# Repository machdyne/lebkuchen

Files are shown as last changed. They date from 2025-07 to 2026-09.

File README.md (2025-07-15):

# Lebkuchen Computer

Lebkuchen is an FPGA computer based on the GateMate A1.

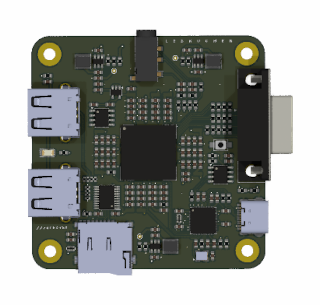
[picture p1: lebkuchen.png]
Lebkuchen


This repo contains schematics, PCB layouts, pinouts, a 3D-printable case, example gateware and documentation.

Find more information on the [Lebkuchen product page](https://machdyne.com/product/lebkuchen-computer/).

## Programming Lebkuchen 

Lebkuchen can be programmed over USB-C or by copying gateware to a MicroSD card (not yet implemented). The FPGA is configured by the onboard RP2040, which can load the configuration from onboard flash, a FAT-formatted MicroSD card or over the USB-JTAG bridge.

### JTAG

Program the FPGA configuration SRAM:

```
openFPGALoader -c dirtyJtag image.bit
```

### 3.5mm TRRS Audio Jack

| Pin | Signal |
| --- | --- |
| T | Left Audio |
| R1 | Right Audio |
| R2 | Composite Video |
| S | GND |

## Resources

 * [fpga-dac audio player](https://github.com/machdyne/fpga-dac)

## License

The contents of this repo are released under the [Lone Dynamics Open License](LICENSE.md).

Note: You can use these designs for commercial purposes but we ask that instead of producing exact clones, that you either replace our trademarks and logos with your own or add your own next to ours.

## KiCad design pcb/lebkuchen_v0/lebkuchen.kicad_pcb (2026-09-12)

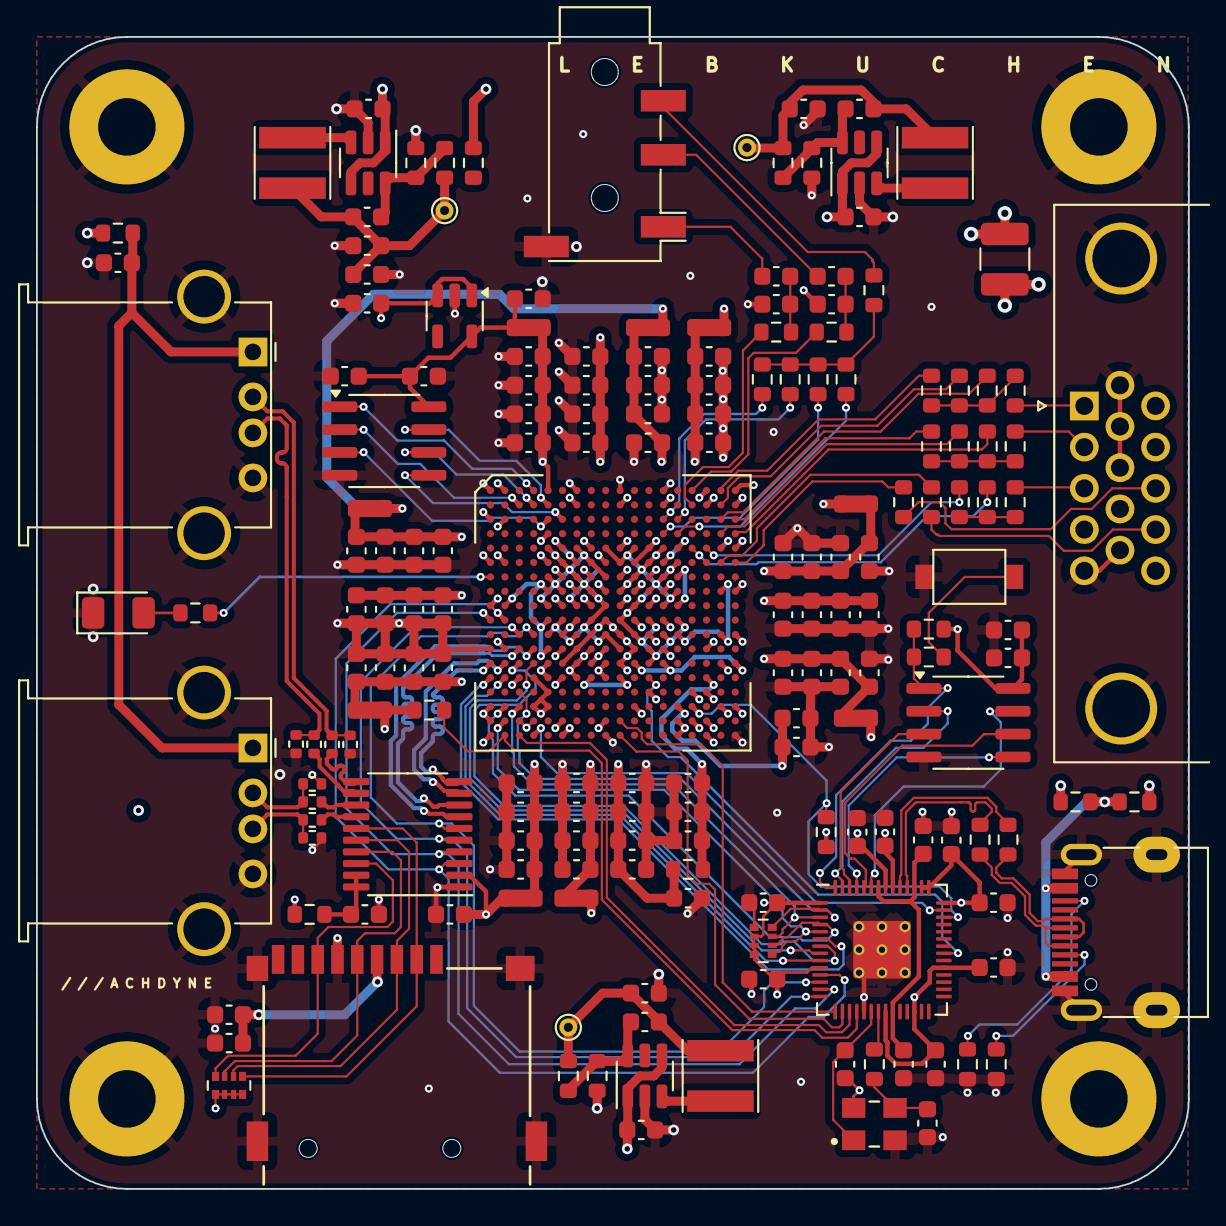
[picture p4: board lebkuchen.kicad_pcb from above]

Board: 4 copper layers, 64.0 x 64.0 mm, 185 parts (0 on the bottom side), 116 nets.

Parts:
C1, C2, C3, C12, C16, C18, C19, C27, C28, C36, C37, C45, C46, C55, C56: 2.2uF; C_0603_1608Metric
C4, C5, C6, C21, C22, C29, C30, C38, C39, C47, C48, C57, C58: 470nF; C_0603_1608Metric
C7: 220nF; C_0603_1608Metric
C8, C9, C10, C11, C17, C20, C23, C24, C31, C32, C40, C41, C49, C50, C59, C60, C64, C65, C67, C68, C69, C71, C83, C84, C85, C86, C87, C88, C90, C91, C95: 100nF; C_0603_1608Metric
C13, C14, C15, C25, C26, C33, C34, C42, C43, C51, C52, C61, C62: 10nF; C_0603_1608Metric
C35, C66, C89, C96, C97: 1uF; C_0603_1608Metric
C44, C80, C81: 22uF; C_0603_1608Metric
C53, C78, C79, C92, C93, C94: 10uF; C_0603_1608Metric
C54, C63: 15pF; C_0603_1608Metric
C72, C73, C74: 4.7uF; C_0603_1608Metric
C75, C76, C77: 10pF; C_0603_1608Metric
D2: LED; LED_1206_3216Metric
F1: Polyfuse; Fuse_1210_3225Metric
FB1, FB2, FB3, FB4: Ferrite_Bead; R_0603_1608Metric
H1, H2, H3, H4: MountingHole_Pad; MountingHole_3.2mm_M3_Pad
J1: TYPE-C-31-M-12-FIXED; USB_C_Receptacle_HRO_TYPE-C-31-M-12-BIG-PADS-PASTE
J3: AudioJack4; Jack_3.5mm_PJ320D_Horizontal
J4: MICROSD; SDCARD
J5, J6: USB_A; USB_A_Stewart_SS-52100-001_Horizontal
L1, L2, L3: 2.2uH; L_Taiyo-Yuden_MD-4040
R1: 4K7; R_0603_1608Metric
R2, R20: 5K1; R_0603_1608Metric
R6, R38: 10K; R_0603_1608Metric
R9, R11, R12, R13, R14, R16, R17, R18, R19: 0R; LD-NETTIE-0603
R10, R15: 27R; R_0603_1608Metric
R23, R24: 200K; R_0603_1608Metric
R25: 44K2; R_0603_1608Metric
R26, R29: 150K; R_0603_1608Metric
R27: 47K; R_0603_1608Metric
R28: 100K; R_0603_1608Metric
R30: 22R; R_0603_1608Metric
R31, R32, R33, R34: 22R; R_0402_1005Metric
R37, R39, R44, R51, R54, R58: 1K; R_0603_1608Metric
R40, R41, R67, R68: 100R; R_0603_1608Metric
R42, R52, R56, R60: 270R; R_0603_1608Metric
R43, R53, R57, R61: 536R; R_0603_1608Metric
R45: 2K; R_0603_1608Metric
R47, R64, R65, R66: 51R; R_0603_1608Metric
R55, R59, R62, R63: 15K; R_0402_1005Metric
RN1: 20K; R_Array_Convex_4x0402
RN2: 4K7; R_Array_Convex_4x0402
SW1: BOOT; Button_2P_3x4mm
TP1: TP_PWR3V3; TestPoint_THTPad_D1.0mm_Drill0.5mm
TP2: TP_PWR2V5; TestPoint_THTPad_D1.0mm_Drill0.5mm
TP3: TP_PWR1V0; TestPoint_THTPad_D1.0mm_Drill0.5mm
U1: CCGM1A1; BGA-324_15.0x15.0mm_Layout18x18_P0.8mm_Ball0.5mm_Pad0.4mm_N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
U2: RP2040; RP2040-QFN-56-OFFICIAL
U3: APS6404L-SQN-SN; SOIC-8_3.9x4.9mm_P1.27mm
U4: LSF0108PWR; TSSOP-20_4.4x6.5mm_P0.65mm
U5: AT25FF321A-SSHN-B; SOIC-8_3.9x4.9mm_P1.27mm
U7: NCP164ASN180T1G; TSOT-23-5
U8, U9, U10: TLV62569DDC; SOT-23-6
VGA1: DB15_Female_MountingHoles; DSUB-15-HD_Female_Horizontal_P2.29x1.98mm_EdgePinOffset3.03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
Y2: ECS-80-12-33-JGN-TR-12MHZ; XTAL_ECS-240-8-33-AGN-TR

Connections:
/AUDIO_L: R40.1, U1.B15 (IO_EB_A8)
/AUDIO_LC: C92.1, J3.T
/AUDIO_R: R41.1, U1.A15 (IO_EB_B8)
/AUDIO_RC: C93.1, J3.R1
/BOOT: R39.1, SW1.1
/CDONE: U1.V3 (IO_WA_B2/CFG_DONE), U2.17 (GPIO14)
/CFAILED: R1.2, U1.V2 (IO_WA_A2/~CFG_FAILED), U2.18 (GPIO15)
/CFG_MD3: U1.V4 (CFG_MD3/IO_WA_B1), U2.41 (GPIO29/ADC3)
/CLKRP: U1.P12 (CLK1/IO_SB_A7), U2.35 (GPIO23)
/CSPI_MISO: U1.P1 (IO_WA_A7/SPI_D1), U2.6 (GPIO4)
/CSPI_MOSI: U1.P2 (IO_WA_B7/SPI_D0), U2.9 (GPIO7)
/CSPI_SCK: U1.N4 (IO_WA_B8/SPI_CLK), U2.8 (GPIO6)
/CSPI_SS: U1.N3 (IO_WA_A8/~SPI_CS), U2.7 (GPIO5)
/JTAG_TCK: RN2.4 (R4.1), U1.R3 (JTAG_TCK/IO_WA_A5), U2.2 (GPIO0)
/JTAG_TDI: RN2.2 (R2.1), U1.T2 (JTAG_TDI/IO_WA_A4), U2.4 (GPIO2)
/JTAG_TDO: RN2.1 (R1.1), U1.U2 (JTAG_TDO/IO_WA_B3), U2.5 (GPIO3)
/JTAG_TMS: RN2.3 (R3.1), U1.T3 (JTAG_TMS/IO_WA_B4), U2.3 (GPIO1)
/LED: R51.1, U1.G1 (IO_WC_A0)
/PWR1V0: C1.2, C2.2, C4.2, C5.2, C9.2, C10.2, C13.2, C14.2, C18.2, C19.2, C20.2, C21.2, C22.2, C23.2, C24.2, C25.2, C26.2, C77.1, C80.1, C81.1, L3.2, R28.1, R30.2, TP3.1, U1.F9 (VDD), U1.G6 (VDD), U1.G8 (VDD), U1.G10 (VDD), U1.G12 (VDD), U1.H7 (VDD), U1.H9 (VDD), U1.H11 (VDD), U1.H13 (VDD), U1.J6 (VDD), U1.J8 (VDD), U1.J10 (VDD), U1.J12 (VDD), U1.K7 (VDD), U1.K9 (VDD), U1.K11 (VDD), U1.K13 (VDD), U1.L6 (VDD), U1.L8 (VDD), U1.L10 (VDD), U1.L12 (VDD), U1.M7 (VDD), U1.M9 (VDD), U1.M11 (VDD), U1.M13 (VDD), U1.N6 (VDD), U1.N8 (VDD), U1.N10 (VDD)
/PWR1V0RP: C64.1, C68.1, U2.23 (DVDD), U2.45 (VREG_VOUT), U2.50 (DVDD)
/PWR1V8: C17.1, C35.1, C97.1, R11.2, U3.8 (VCC), U7.5 (OUT)
/PWR2V5: C8.2, C16.2, C66.1, C69.1, C71.1, C76.1, C79.1, C83.1, C84.1, C85.1, C86.1, C87.1, C88.1, C89.1, L2.2, R1.1, R6.1, R9.2, R12.2, R13.2, R14.2, R16.2, R17.2, R18.2, R19.2, R26.1, R38.1, RN2.6 (R3.2), RN2.7 (R2.2), RN2.8 (R1.2), TP2.1, U1.T14 (VDD_CLK), U2.1 (IOVDD), U2.10 (IOVDD), U2.22 (IOVDD), U2.26 (RUN), U2.33 (IOVDD), U2.42 (IOVDD), U2.43 (ADC_AVDD), U2.44 (VREG_VIN), U2.49 (IOVDD), U4.2 (VREF_A), U5.8 (VCC)
/PWR3V3: C65.1, C75.1, C78.1, C94.1, C95.1, C96.1, J4.4 (VDD), L1.2, R23.1, R24.1, RN1.5 (R4.2), RN1.6 (R3.2), RN1.7 (R2.2), RN1.8 (R1.2), TP1.1, U2.48 (USB_VDD), U7.1 (IN), U7.3 (EN)
/PWR5V0: C72.1, C73.1, C74.1, F1.2, FB3.1, FB4.1, U8.1 (EN), U8.4 (VIN), U9.1 (EN), U9.4 (VIN), U10.1 (EN), U10.4 (VIN)
/PWR5V0R: F1.1, FB1.1, FB2.1
/RAM_IO2: U1.C5 (IO_NA_B2), U3.3 (SIO2)
/RAM_IO3: U1.B5 (IO_NA_A2), U3.7 (SIO3)
/RAM_MISO: U1.B3 (IO_NA_B0), U3.2 (SO/SIO)
/RAM_MOSI: U1.C6 (IO_NA_A3), U3.5 (SI/SIO)
/RAM_SCK: U1.B4 (IO_NA_B1), U3.6 (SCLK)
/RAM_SS: U1.A4 (IO_NA_A1), U3.1 (~CE)
/RESETN: R6.2, U1.T15 (~RESET), U2.40 (GPIO28/ADC2)
/RP_QSPI_IO0: U2.53 (QSPI_SD0), U5.5 (DI(IO0))
/RP_QSPI_IO1: U2.55 (QSPI_SD1), U5.2 (DO(IO1))
/RP_QSPI_IO2: U2.54 (QSPI_SD2), U5.3 (IO2)
/RP_QSPI_IO3: U2.51 (QSPI_SD3), U5.7 (IO3)
/RP_QSPI_SCK: U2.52 (QSPI_SCLK), U5.6 (CLK)
/RP_QSPI_SS: R38.2, R39.2, U2.56 (QSPI_CSN), U5.1 (~CS)
/SDC_MISO: J4.7 (DAT0), RN1.4 (R4.1), U4.18 (B1)
/SDC_MOSI: J4.3 (CMD), RN1.2 (R2.1), U4.16 (B3)
/SDC_SCK: J4.5 (CLK), RN1.3 (R3.1), U4.17 (B2)
/SDC_SS: J4.2 (DAT3/CD), RN1.1 (R1.1), U4.15 (B4)
/SD_MISO: U1.K2 (IO_WB_B5), U2.11 (GPIO8), U4.3 (A1)
/SD_MOSI: U1.L3 (IO_WB_A2), U2.14 (GPIO11), U4.5 (A3)
/SD_SCK: U1.K1 (IO_WB_A5), U2.13 (GPIO10), U4.4 (A2)
/SD_SS: U1.L4 (IO_WB_B2), U2.12 (GPIO9), U4.6 (A4)
/UART_RX: U1.V10 (IO_SA_B8), U2.16 (GPIO13)
/UART_TX: U1.U10 (IO_SA_A8), U2.15 (GPIO12)
/USB1C_DN: R32.2, U4.13 (B6)
/USB1C_DP: R31.2, U4.14 (B5)
/USB1_CONN_DN: J6.2 (D-), R32.1, R59.1
/USB1_CONN_DP: J6.3 (D+), R31.1, R55.1
/USB1_DN: U1.M3 (IO_WB_A1), U4.8 (A6)
/USB1_DP: U1.M4 (IO_WB_B1), U4.7 (A5)
/USB2C_DN: R34.2, U4.11 (B8)
/USB2C_DP: R33.2, U4.12 (B7)
/USB2_CONN_DN: J5.2 (D-), R34.1, R63.1
/USB2_CONN_DP: J5.3 (D+), R33.1, R62.1
/USB2_DN: U1.N1 (IO_WB_A0), U4.10 (A8)
/USB2_DP: U1.N2 (IO_WB_B0), U4.9 (A7)
/USB_CONN_DN: J1.A7 (DN1), J1.B7 (DN2), R10.1
/USB_CONN_DP: J1.A6 (DP1), J1.B6 (DP2), R15.1
/USB_DN: R10.2, U2.46 (USB_DM)
/USB_DP: R15.2, U2.47 (USB_DP)
/VBUS: C53.1, FB3.2, J5.1 (VBUS), J6.1 (VBUS)
/VBUSC: FB1.2, FB2.2, J1.A4 (VBUS), J1.A9 (VBUS), J1.B4 (VBUS), J1.B9 (VBUS)
/VDD_EA: C37.2, C39.2, C41.2, C43.2, R14.1, U1.G14 (VDD_EA), U1.H17 (VDD_EA), U1.J14 (VDD_EA), U1.L14 (VDD_EA), U1.L17 (VDD_EA)
/VDD_EB: C36.2, C38.2, C40.2, C42.2, R13.1, U1.A16 (VDD_EB), U1.B18 (VDD_EB), U1.E14 (VDD_EB), U1.E17 (VDD_EB), U1.F13 (VDD_EB)
/VDD_NA: C27.2, C29.2, C31.2, C33.2, R11.1, U1.A5 (VDD_NA), U1.B7 (VDD_NA), U1.E6 (VDD_NA), U1.E8 (VDD_NA), U1.F7 (VDD_NA)
/VDD_NB: C28.2, C30.2, C32.2, C34.2, R12.1, U1.B10 (VDD_NB), U1.B13 (VDD_NB), U1.E10 (VDD_NB), U1.E12 (VDD_NB), U1.F11 (VDD_NB)
/VDD_PLL: C7.2, C12.2, C44.2, R30.1, U1.P16 (VDD_PLL)
/VDD_SA: C46.2, C48.2, C50.2, C52.2, R17.1, U1.P6 (VDD_SA), U1.P8 (VDD_SA), U1.P10 (VDD_SA), U1.U6 (VDD_SA), U1.U9 (VDD_SA)
/VDD_SB: C45.2, C47.2, C49.2, C51.2, R16.1, U1.N11 (VDD_SB), U1.N13 (VDD_SB), U1.N18 (VDD_SB), U1.R15 (VDD_SB), U1.T18 (VDD_SB)
/VDD_WA: C3.2, C6.2, C11.2, C15.2, R9.1, U1.N5 (VDD_WA), U1.P3 (VDD_WA), U1.P5 (VDD_WA), U1.T1 (VDD_WA), U1.U1 (POR_EN/IO_WA_A3), U1.U3 (VDD_WA), U1.U4 (CFG_MD2/IO_WA_A1)
/VDD_WB: C56.2, C58.2, C60.2, C62.2, R19.1, U1.H5 (VDD_WB), U1.J2 (VDD_WB), U1.K5 (VDD_WB), U1.M2 (VDD_WB), U1.M5 (VDD_WB)
/VDD_WC: C55.2, C57.2, C59.2, C61.2, R18.1, U1.A2 (VDD_WC), U1.C2 (VDD_WC), U1.D5 (VDD_WC), U1.F2 (VDD_WC), U1.F5 (VDD_WC)
/VGA_B0: R60.2, U1.E16 (IO_EB_A3)
/VGA_B1: R61.2, U1.E15 (IO_EB_B3)
/VGA_BLUE: R60.1, R61.1, R66.2
/VGA_B_CONN: R66.1, VGA1.3
/VGA_G0: R56.2, U1.C18 (IO_EB_A4)
/VGA_G1: R57.2, U1.D17 (IO_EB_B2)
/VGA_G2: R58.2, U1.D18 (IO_EB_A2)
/VGA_GREEN: R56.1, R57.1, R58.1, R65.2
/VGA_G_CONN: R65.1, VGA1.2
/VGA_HS: R67.2, U1.F18 (IO_EB_A0)
/VGA_HS_CONN: R67.1, VGA1.13
/VGA_R0: R52.2, U1.A17 (IO_EB_B5)
/VGA_R1: R53.2, U1.B17 (IO_EB_A5)
/VGA_R2: R54.2, U1.C17 (IO_EB_B4)
/VGA_RED: R52.1, R53.1, R54.1, R64.2
/VGA_R_CONN: R64.1, VGA1.1
/VGA_VS: R68.2, U1.F17 (IO_EB_B0)
/VGA_VS_CONN: R68.1, VGA1.14
/VIDEO_C: J3.R2, R47.2
/VIDEO_D0: R42.1, U1.C13 (IO_NB_B6)
/VIDEO_D1: R43.1, U1.C14 (IO_NB_B8)
/VIDEO_D2: R44.1, U1.D13 (IO_NB_A6)
/VIDEO_D3: R45.1, U1.D14 (IO_NB_A8)
/XIN: C54.2, U2.20 (XIN), Y2.1 (IN/OUT)
/XOUT: R37.2, U2.21 (XOUT)
GND: C1.1, C2.1, C3.1, C4.1, C5.1, C6.1, C7.1, C8.1, C9.1, C10.1, C11.1, C12.1, C13.1, C14.1, C15.1, C16.1, C17.2, C18.1, C19.1, C20.1, C21.1, C22.1, C23.1, C24.1, C25.1, C26.1, C27.1, C28.1, C29.1, C30.1, C31.1, C32.1, C33.1, C34.1, C35.2, C36.1, C37.1, C38.1, C39.1, C40.1, C41.1, C42.1, C43.1, C44.1, C45.1, C46.1, C47.1, C48.1, C49.1, C50.1, C51.1, C52.1, C53.2, C54.1, C55.1, C56.1, C57.1, C58.1, C59.1, C60.1, C61.1, C62.1, C63.2, C64.2, C65.2, C66.2, C67.2, C68.2, C69.2, C71.2, C72.2, C73.2, C74.2, C78.2, C79.2, C80.2, C81.2, C83.2, C84.2, C85.2, C86.2, C87.2, C88.2, C89.2, C90.2, C91.2, C94.2, C95.2, C96.2, C97.2, D2.1 (K), H1.1, H2.1, H3.1, H4.1, J1.A1 (GND), J1.A12 (GND), J1.B1 (GND), J1.B12 (GND), J1.S1 (SHIELD), J1.S2 (SHIELD), J1.S3 (SHIELD), J1.S4 (SHIELD), J3.S, J4.6 (VSS), J5.4 (GND), J5.5 (Shield), J6.4 (GND), J6.5 (Shield), R2.2, R20.2, R25.2, R27.2, R29.2, R55.2, R59.2, R62.2, R63.2, RN2.5 (R4.2), SW1.2, U1.A1 (GND), U1.A7 (GND), U1.A10 (GND), U1.A13 (GND), U1.A18 (GND), U1.B16 (GND), U1.C1 (GND), U1.E5 (GND), U1.E7 (GND), U1.E9 (GND), U1.E11 (GND), U1.E13 (GND), U1.E18 (GND), U1.F1 (GND), U1.F6 (GND), U1.F8 (GND), U1.F10 (GND), U1.F12 (GND), U1.F14 (GND), U1.G5 (GND), U1.G7 (GND), U1.G9 (GND), U1.G11 (GND), U1.G13 (GND), U1.H6 (GND), U1.H8 (GND), U1.H10 (GND), U1.H12 (GND), U1.H14 (GND), U1.H18 (GND), U1.J1 (GND), U1.J5 (GND), U1.J7 (GND), U1.J9 (GND), U1.J11 (GND), U1.J13 (GND), U1.K6 (GND), U1.K8 (GND), U1.K10 (GND), U1.K12 (GND), U1.K14 (GND), U1.L5 (GND), U1.L7 (GND), U1.L9 (GND), U1.L11 (GND), U1.L13 (GND), U1.L18 (GND), U1.M1 (GND), U1.M6 (GND), U1.M8 (GND), U1.M10 (GND), U1.M12 (GND), U1.M16 (GND), U1.N7 (GND), U1.N9 (GND), U1.N12 (GND), U1.N17 (GND), U1.P4 (GND), U1.P7 (GND), U1.P9 (GND), U1.R5 (CFG_MD0/IO_WA_A0), U1.R12 (GND), U1.R16 (GND), U1.T4 (GND), U1.T5 (CFG_MD1/IO_WA_B0), U1.T11 (GND), U1.T17 (GND), U1.U14 (GND), U1.U15 (GND), U1.U16 (GND), U1.V1 (GND), U1.V6 (GND), U1.V9 (GND), U1.V14 (GND), U1.V16 (GND), U1.V18 (GND), U2.19 (TESTEN), U2.57 (GND), U3.4 (VSS), U4.1 (GND), U5.4 (GND), U7.2 (GND), U8.2 (GND), U9.2 (GND), U10.2 (GND), VGA1.0 (PAD), VGA1.5, VGA1.6, VGA1.7, VGA1.8, VGA1.10, Y2.2 (GND), Y2.4 (GND)
unnamed: C90.1, C92.2, R40.2
unnamed: C91.1, C93.2, R41.2
unnamed: D2.2 (A), R51.2
unnamed: J1.A5 (CC1), R2.1
unnamed: J1.B5 (CC2), R20.1
unnamed: R42.2, R43.2, R44.2, R45.2, R47.1
unnamed: C67.1, R23.2, U4.19 (VREF_B), U4.20 (EN)
unnamed: C75.2, R24.2, R25.1, U8.6 (FB)
unnamed: L1.1, U8.3 (SW)
unnamed: C76.2, R26.2, R27.1, U9.6 (FB)
unnamed: L2.1, U9.3 (SW)
unnamed: C77.2, R28.2, R29.1, U10.6 (FB)
unnamed: L3.1, U10.3 (SW)
unnamed: C63.1, R37.1, Y2.3 (OUT/IN)

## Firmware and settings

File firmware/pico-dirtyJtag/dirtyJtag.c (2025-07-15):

#include <stdio.h>
#include "pico/stdlib.h"
#include "pico/binary_info.h"
#include "hardware/pio.h"
#include "pico/multicore.h"
#include "dirtyJtagConfig.h"
#include "pio_jtag.h"
#include "bsp/board.h"
#include "tusb.h"
#include "cmd.h"
#include "get_serial.h"
#include "hardware/clocks.h"
#include "hardware/structs/pll.h"
#include "hardware/structs/clocks.h"

#define MULTICORE

void init_pins()
{
    bi_decl(bi_4pins_with_names(PIN_TCK, "TCK", PIN_TDI, "TDI", PIN_TDO, "TDO", PIN_TMS, "TMS"));
    #if !( BOARD_TYPE == BOARD_QMTECH_RP2040_DAUGHTERBOARD )
    bi_decl(bi_2pins_with_names(PIN_RST, "RST", PIN_TRST, "TRST"));
    #endif
}

pio_jtag_inst_t jtag = {
            .pio = pio0,
            .sm = 0
};

void djtag_init()
{
    init_pins();
    init_jtag(&jtag, 1000, PIN_TCK, PIN_TDI, PIN_TDO, PIN_TMS, 255, 255);

    gpio_init(PIN_CFG_MD3);
    gpio_init(PIN_CRESET);
    gpio_init(PIN_CDONE);
    gpio_init(PIN_CFAILED);

    gpio_set_dir(PIN_CFG_MD3, 1); // set as output
    gpio_set_dir(PIN_CRESET, 1); // set as output

	clock_gpio_init(PIN_CLK, CLOCKS_CLK_GPOUT1_CTRL_AUXSRC_VALUE_CLK_USB, 1);

    // enter JTAG mode
    gpio_put(PIN_CFG_MD3, 1);

    // toggle CRESET
    gpio_put(PIN_CRESET, 0);
    sleep_ms(250);
    gpio_put(PIN_CRESET, 1);

}
typedef uint8_t cmd_buffer[64];
static uint wr_buffer_number = 0;
static uint rd_buffer_number = 0; 
typedef struct buffer_info
{
    volatile uint8_t count;
    volatile uint8_t busy;
    cmd_buffer buffer;
} buffer_info;

#define n_buffers (4)

buffer_info buffer_infos[n_buffers];

static cmd_buffer tx_buf;

void jtag_main_task()
{
#ifdef MULTICORE
    if (multicore_fifo_rvalid())
    {
        //some command processing has been done
        uint rx_num = multicore_fifo_pop_blocking();
        buffer_info* bi = &buffer_infos[rx_num];
        bi->busy = false;

    }
#endif
    if ((buffer_infos[wr_buffer_number].busy == false)) 
    {
        //If tud_task() is called and tud_vendor_read isn't called immediately (i.e before calling tud_task again)
        //after there is data available, there is a risk that data from 2 BULK OUT transaction will be (partially) combined into one
        //The DJTAG protocol does not tolerate this. 
        tud_task();// tinyusb device task
        if (tud_vendor_available())
        {
            led_rx( 1 );
            uint bnum = wr_buffer_number;
            uint count = tud_vendor_read(buffer_infos[wr_buffer_number].buffer, 64);
            if (count != 0)
            {
                buffer_infos[bnum].count = count;
                buffer_infos[bnum].busy = true;
                wr_buffer_number = wr_buffer_number + 1; //switch buffer
                if (wr_buffer_number == n_buffers)
                {
                    wr_buffer_number = 0; 
                }
#ifdef MULTICORE
                multicore_fifo_push_blocking(bnum);
#endif
            }
            led_rx( 0 );
        } else {
#if ( USB_CDC_UART_BRIDGE )           
            cdc_uart_task();
#endif
        }
    }
}

void jtag_task()
{
#ifndef MULTICORE
    jtag_main_task();
#endif
}

#ifdef MULTICORE
void core1_entry() {

    djtag_init();
    while (1)
    {
        uint rx_num = multicore_fifo_pop_blocking();
        buffer_info* bi = &buffer_infos[rx_num];
        assert (bi->busy);
        cmd_handle(&jtag, bi->buffer, bi->count, tx_buf);
        multicore_fifo_push_blocking(rx_num);
    }
 
}
#endif

void fetch_command()
{
#ifndef MULTICORE
    if (buffer_infos[rd_buffer_number].busy)
    {
        cmd_handle(&jtag, buffer_infos[rd_buffer_number].buffer, buffer_infos[rd_buffer_number].count, tx_buf);
        buffer_infos[rd_buffer_number].busy = false;
        rd_buffer_number++; //switch buffer
        if (rd_buffer_number == n_buffers)
        {
            rd_buffer_number = 0; 
        }
    }
#endif
}

//this is to work around the fact that tinyUSB does not handle setup request automatically
//Hence this boiler plate code
bool tud_vendor_control_xfer_cb(uint8_t rhport, uint8_t stage, tusb_control_request_t const * request)
{
    if (stage != CONTROL_STAGE_SETUP) return true;
    return false;
}

int main()
{
    board_init();
    usb_serial_init();
    tusb_init();

    led_init( LED_INVERTED, PIN_LED_TX, PIN_LED_RX, PIN_LED_ERROR );
#if ( USB_CDC_UART_BRIDGE )
    cdc_uart_init( PIN_UART, PIN_UART_RX, PIN_UART_TX );
#endif

#ifdef MULTICORE
    multicore_launch_core1(core1_entry);
#else 
    djtag_init();
#endif
    while (1) {
        jtag_main_task();
        fetch_command();//for unicore implementation
    }
}

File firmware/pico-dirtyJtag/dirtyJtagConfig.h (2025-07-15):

#ifndef DirtyJtagConfig_h
#define DirtyJtagConfig_h

// Set to 0 to disable USB-CDC-UART bridge
#define USB_CDC_UART_BRIDGE  1


#define BOARD_PICO           0
#define BOARD_ADAFRUIT_ITSY  1
#define BOARD_SPOKE_RP2040   2
#define BOARD_QMTECH_RP2040_DAUGHTERBOARD 3
#define BOARD_WERKZEUG       4
#define BOARD_LEBKUCHEN         100

// Select the board type from the above
#define BOARD_TYPE BOARD_LEBKUCHEN
//#define BOARD_TYPE BOARD_ADAFRUIT_ITSY
//#define BOARD_TYPE BOARD_SPOKE_RP2040
//#define BOARD_TYPE BOARD_WERKZEUG
//#define BOARD_TYPE BOARD_QMTECH_RP2040_DAUGHTERBOARD

// General mapping
// TDI  SPIO RX
// TDO  SPIO TX
// TCK  SPIO SCK
// TMS  SPIO CS
// RST  GPIO
// TRST GPIO

#if ( BOARD_TYPE == BOARD_PICO )

#define PIN_TDI 16 
#define PIN_TDO 17
#define PIN_TCK 18
#define PIN_TMS 19
#define PIN_RST 20
#define PIN_TRST 21

#define LED_INVERTED   0
#define PIN_LED_TX     25
#define PIN_LED_ERROR  25
#define PIN_LED_RX     25

#if ( USB_CDC_UART_BRIDGE )
#define PIN_UART       uart0
#define PIN_UART_TX    12
#define PIN_UART_RX    13
#endif // USB_CDC_UART_BRIDGE

#elif ( BOARD_TYPE == BOARD_ADAFRUIT_ITSY )

#define PIN_TDI 28 
#define PIN_TDO 27
#define PIN_TCK 26
#define PIN_TMS 29
#define PIN_RST 24
#define PIN_TRST 25

// no regular LEDs on the Itsy - it's a neopixel
#define LED_INVERTED   0
#define PIN_LED_TX     -1
#define PIN_LED_ERROR  -1
#define PIN_LED_RX     -1

#if ( USB_CDC_UART_BRIDGE )
#define PIN_UART       uart0
#define PIN_UART_TX    0
#define PIN_UART_RX    1
#endif // USB_CDC_UART_BRIDGE

#elif ( BOARD_TYPE == BOARD_SPOKE_RP2040 )

#define PIN_TDI 23 
#define PIN_TDO 20
#define PIN_TCK 22
#define PIN_TMS 21
#define PIN_RST 26
#define PIN_TRST 27

#define LED_INVERTED   1
#define PIN_LED_TX     16
#define PIN_LED_ERROR  17
#define PIN_LED_RX     18

#if ( USB_CDC_UART_BRIDGE )
#define PIN_UART       uart0
#define PIN_UART_TX    28
#define PIN_UART_RX    29
#endif // USB_CDC_UART_BRIDGE


#elif ( BOARD_TYPE == BOARD_WERKZEUG )

#define PIN_TDI 1
#define PIN_TDO 2
#define PIN_TCK 0
#define PIN_TMS 3
#define PIN_RST 4
#define PIN_TRST 5

#define LED_INVERTED   1
#define PIN_LED_TX     20
#define PIN_LED_ERROR  21
#define PIN_LED_RX     20

#if ( USB_CDC_UART_BRIDGE )
#define PIN_UART       uart0
#define PIN_UART_TX    28
#define PIN_UART_RX    29
#endif // USB_CDC_UART_BRIDGE

#elif ( BOARD_TYPE == BOARD_LEBKUCHEN )

#define PIN_TCK 0
#define PIN_TDI 2
#define PIN_TDO 3
#define PIN_TMS 1

#define PIN_RST 8
#define PIN_TRST 9

#define PIN_CDONE		14
#define PIN_CFAILED	15
#define PIN_CRESET	28
#define PIN_CLK		23
#define PIN_CFG_MD3  29

#define LED_INVERTED   0
#define PIN_LED_TX     -1
#define PIN_LED_ERROR  -1
#define PIN_LED_RX     -1

#if ( USB_CDC_UART_BRIDGE )
#define PIN_UART       uart0
#define PIN_UART_TX    12
#define PIN_UART_RX    13
#endif // USB_CDC_UART_BRIDGE


#elif ( BOARD_TYPE == BOARD_QMTECH_RP2040_DAUGHTERBOARD )

// in rp2040 daughterboard UART pins are connected to FPGA pins
// depending on the FPGA pin configuration there is a possibility
// of damage so these pins are not going to be setup
#define USB_CDC_UART_BRIDGE  0

#define PIN_TDI  16 
#define PIN_TDO  17
#define PIN_TCK  18
#define PIN_TMS  19
// in rp2040 daughterboard these pins are connected to FPGA pins
// depending on the FPGA pin configuration there is a possibility
// of damage so these pins are not going to be setup
// #define PIN_RST  X
// #define PIN_TRST X

#define LED_INVERTED   0
#define PIN_LED_TX     25
#define PIN_LED_ERROR  25
#define PIN_LED_RX     25

#endif // BOARD_TYPE

#endif // DirtyJtagConfig_h

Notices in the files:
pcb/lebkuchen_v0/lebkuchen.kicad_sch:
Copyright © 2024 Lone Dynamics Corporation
